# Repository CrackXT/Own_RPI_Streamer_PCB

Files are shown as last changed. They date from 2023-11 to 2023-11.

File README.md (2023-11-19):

# Own_RPI_Streamer_PCB

PCB files for RPI Streamer Board

# Description

This is a main board to hold a Raspberry Pi (4) and the Hifyberry Digi2 Pro expansion board. This puts the connections I need (for me) on one side to be able to build my own streamer.

- Part 1

The internal "power supply" (Pololu S13V30F5) delivers at 5V@3A, sensor and RGB are control by part 2.

There is a temperature sensor (Sensirion SHT45) under the SoC and an additional unregulated fan connector (e.g. Noctua NF-A4x20 5V). In addition there is the possibility to connect a lighting (RGB). Furthermore, the following connections are available... USB-C (power supply), USB-A 3.0 (data, e.g. USB stick with music on it), main switch, QWIIC/StemmaQT (sensor) and an external 5V connector (for part 2).

The board can be produced here (AISLER) with the files (.brd and .sch) or by any other PCB manufacturer. -> https://aisler.net/

# Spec

Vin: 2.8 - 22V<br>
Vout: 5V (typ., min.4,85V, max.5,15V)<br>
Iout: 3A<br>

# Serie

- .pro

# Layout

Top<br>


Bottom<br>


Routing/Dimensions(mm)<br>


Schematic<br>
Schematic as .pdf at the top of the page.

# License

Open hardware, use it, mod it, whatever you want, feel free...

# Thanks!

Own design and layout.

# Version - Build

v1.4 - 06.11.2023

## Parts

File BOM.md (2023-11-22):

# BOM - List

parts list for use<br>
[BOM_Streamer_v1.4.pdf](https://github.com/CrackXT/Own_RPI_Streamer_PCB/files/13402858/BOM_Streamer_v1.4.pdf)
<br>
BOM_Streamer_v1 4

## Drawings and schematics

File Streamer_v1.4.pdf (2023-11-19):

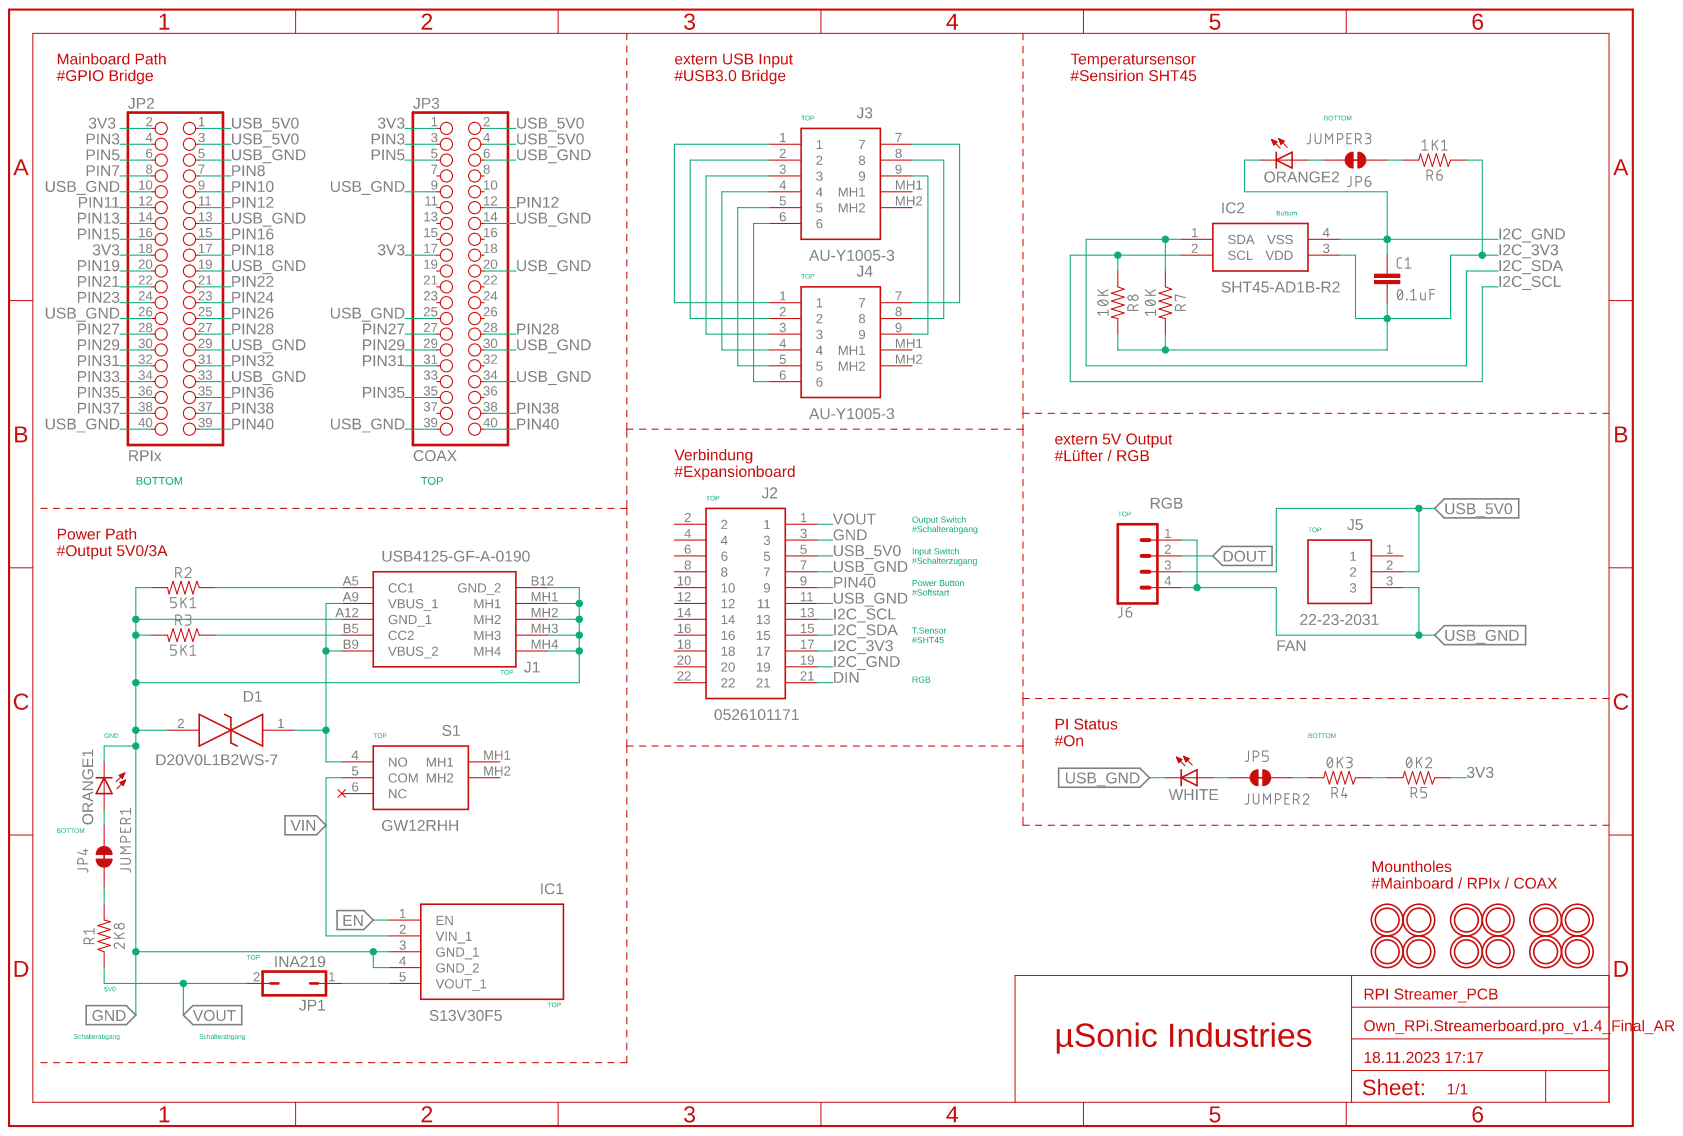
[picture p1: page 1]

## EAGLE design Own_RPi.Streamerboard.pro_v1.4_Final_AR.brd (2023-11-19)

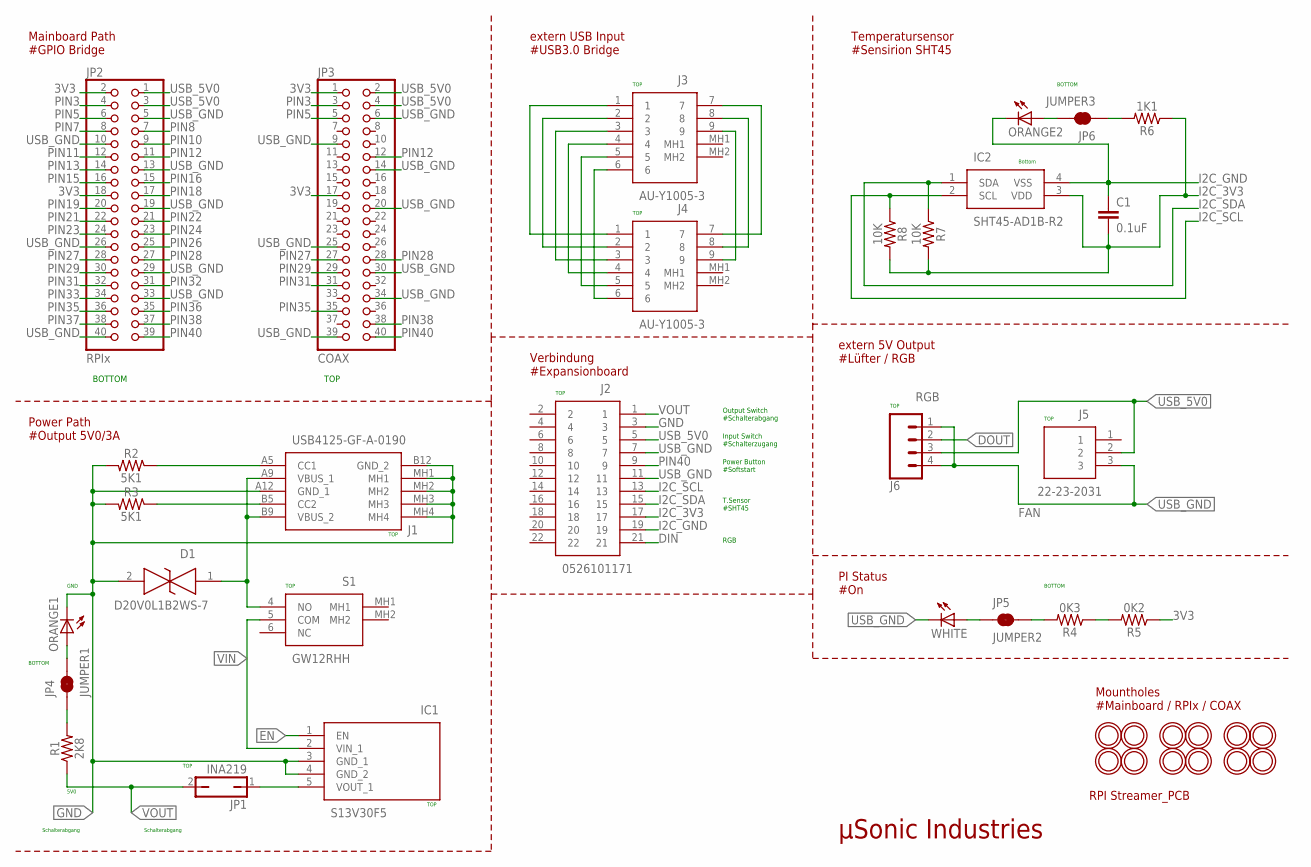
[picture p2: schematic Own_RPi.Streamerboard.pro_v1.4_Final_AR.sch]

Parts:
C1: 0.1uF; 0805
D1: D20V0L1B2WS-7; SOD2513X120N
IC1: S13V30F5
IC2: SHT45-AD1B-R2; SHT45AD1BR2
J1: USB4125-GF-A-0190; USB4125GFA0190
J2: 0526101171
J3, J4: AU-Y1005-3; AUY10053
J5: 22-23-2031; SHDR3W82P0X254_1X3_747X635X818
J6: CONN_041X04_NO_SILK; 1X04_NO_SILK
JP1: INA219; 1X02_NO_SILK
JP2: RPIx; 2X20-BIG
JP3: COAX; 2X20-BIG
JP4: JUMPER1; SMT-JUMPER_2_NC_TRACE_SILK
JP5: JUMPER2; SMT-JUMPER_2_NC_TRACE_SILK
JP6: JUMPER3; SMT-JUMPER_2_NC_TRACE_SILK
ORANGE1, ORANGE2: LEDCHIPLED_0805; CHIPLED_0805
R1: 2K8; 0805
R2, R3: 5K1; 0805
R4: 0K3; 0805
R5: 0K2; 0805
R6: 1K1; 0805
R7, R8: 10K; 0805
S1: GW12RHH
U$4, U$5, U$6, U$7, U$8, U$10, U$11, U$13, U$14, U$15, U$16, U$17: MOUNTINGHOLE2.5; MOUNTINGHOLE_2.5_PLATED
WHITE: LEDCHIPLED_0805; CHIPLED_0805

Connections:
3V3: JP2.2, JP2.18, JP3.1, JP3.17, R5.1
DIN: J2.21
DOUT: J6.2
EN: IC1.1 (EN)
GND: D1.2, IC1.3 (GND_1), IC1.4 (GND_2), J1.A12 (GND_1), J1.B12 (GND_2), J1.MH1, J1.MH2, J1.MH3, J1.MH4, J2.3, ORANGE1.C, R2.2, R3.2
I2C_3V3: C1.2, IC2.3 (VDD), J2.17, R6.1, R7.2, R8.2
I2C_GND: C1.1, IC2.4 (VSS), J2.19, ORANGE2.C
I2C_SCL: IC2.2 (SCL), J2.13, R8.1
I2C_SDA: IC2.1 (SDA), J2.15, R7.1
unnamed: JP4.1, R1.2
unnamed: R4.1, R5.2
unnamed: J1.B5 (CC2), R3.1
unnamed: J1.A5 (CC1), R2.1
unnamed: J3.4, J4.4
unnamed: JP6.2, ORANGE2.A
unnamed: JP5.1, WHITE.A
unnamed: IC1.5 (VOUT_1), JP1.1
unnamed: JP4.2, ORANGE1.A
unnamed: JP5.2, R4.2
unnamed: JP6.1, R6.2
unnamed: J3.6, J4.6
unnamed: J3.5, J4.5
unnamed: J3.3, J4.3
unnamed: J3.2, J4.2
unnamed: J3.1, J4.1
unnamed: J3.9, J4.9
unnamed: J3.8, J4.8
unnamed: J3.7, J4.7
PIN3: JP2.4, JP3.3
PIN5: JP2.6, JP3.5
PIN7: JP2.8
PIN8: JP2.7
PIN10: JP2.9
PIN11: JP2.12
PIN12: JP2.11, JP3.12
PIN13: JP2.14
PIN15: JP2.16
PIN16: JP2.15
PIN18: JP2.17
PIN19: JP2.20
PIN21: JP2.22
PIN22: JP2.21
PIN23: JP2.24
PIN24: JP2.23
PIN26: JP2.25
PIN27: JP2.28, JP3.27
PIN28: JP2.27, JP3.28
PIN29: JP2.30, JP3.29
PIN31: JP2.32, JP3.31
PIN32: JP2.31
PIN33: JP2.34
PIN35: JP2.36, JP3.35
PIN36: JP2.35
PIN37: JP2.38
PIN38: JP2.37, JP3.38
PIN40: J2.9, JP2.39, JP3.40
USB_5V0: J2.5, J5.2, J6.3, JP2.1, JP2.3, JP3.2, JP3.4
USB_GND: J2.7, J2.11, J5.3, J6.1, J6.4, JP2.5, JP2.10, JP2.13, JP2.19, JP2.26, JP2.29, JP2.33, JP2.40, JP3.6, JP3.9, JP3.14, JP3.20, JP3.25, JP3.30, JP3.34, JP3.39, WHITE.C
VBUS_VIN: D1.1, J1.A9 (VBUS_1), J1.B9 (VBUS_2), S1.4 (NO)
VIN: IC1.2 (VIN_1), S1.5 (COM)
VOUT: J2.1, JP1.2, R1.1

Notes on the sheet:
µSonic Industries
RPI Streamer_PCB
Power Path #Output 5V0/3A
TOP
Schalterabgang
BOTTOM
Mountholes #Mainboard / RPIx / COAX
GND
5V0
Temperatursensor #Sensirion SHT45
extern 5V Output #Lüfter / RGB
extern USB Input #USB3.0 Bridge
Mainboard Path #GPIO Bridge
PI Status #On
RGB
Bottom
Power Button #Softstart
Output Switch #Schalterabgang
Input Switch #Schalterzugang
T.Sensor #SHT45
Verbindung #Expansionboard
FAN

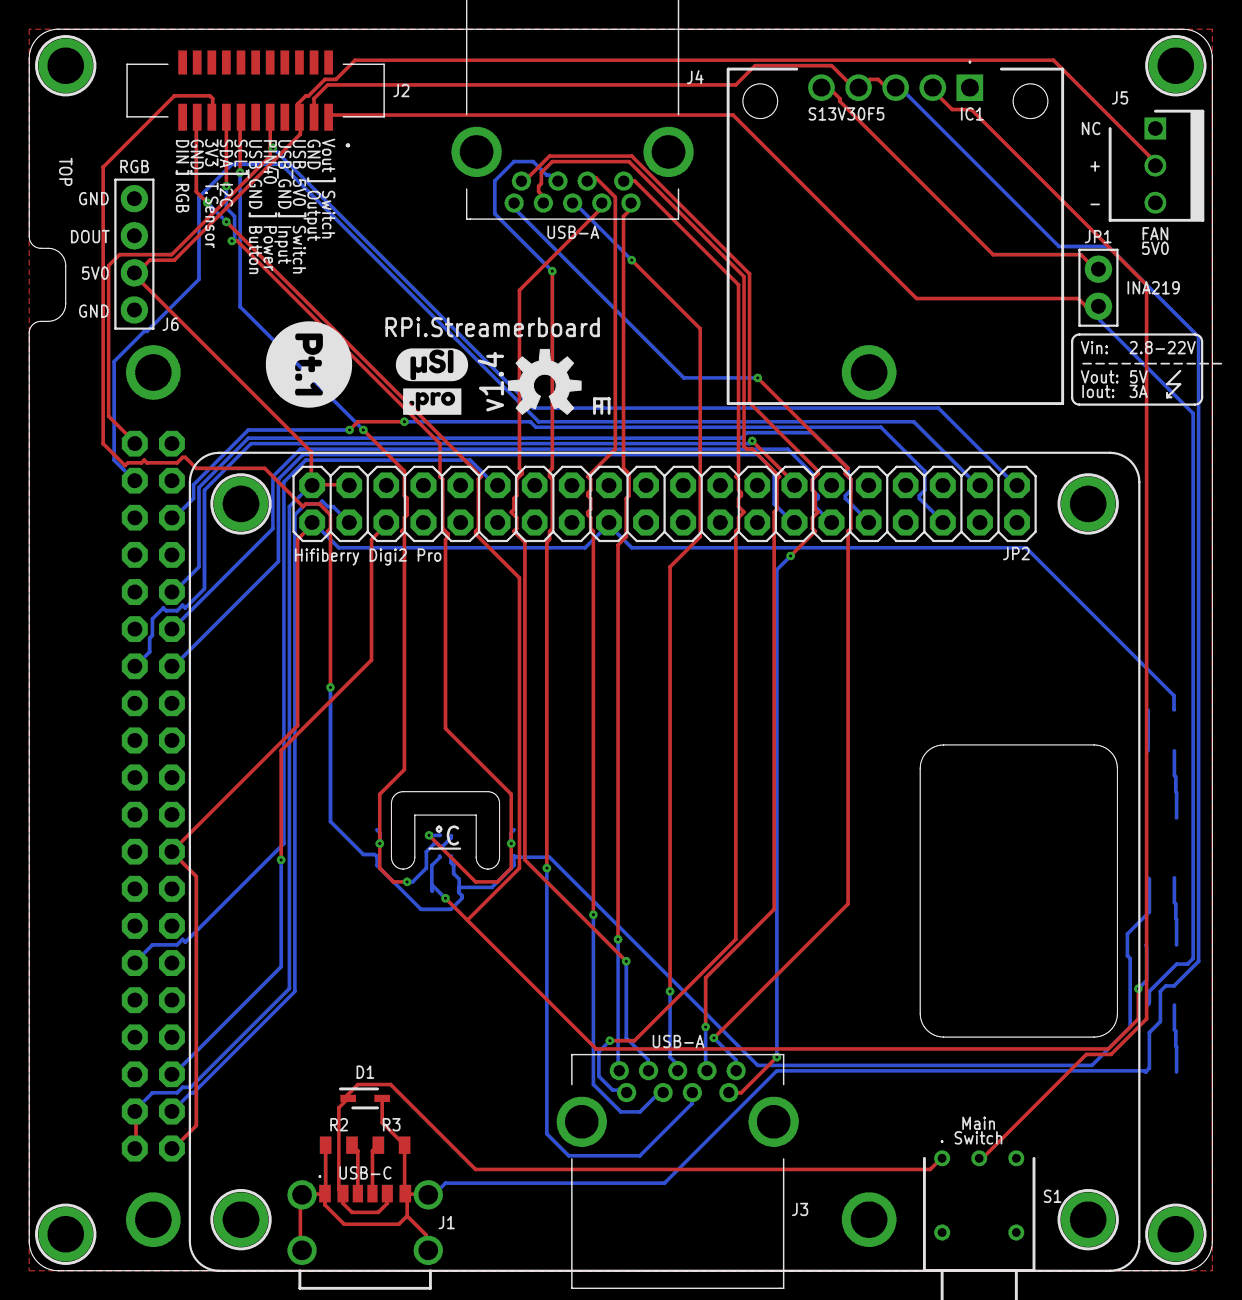
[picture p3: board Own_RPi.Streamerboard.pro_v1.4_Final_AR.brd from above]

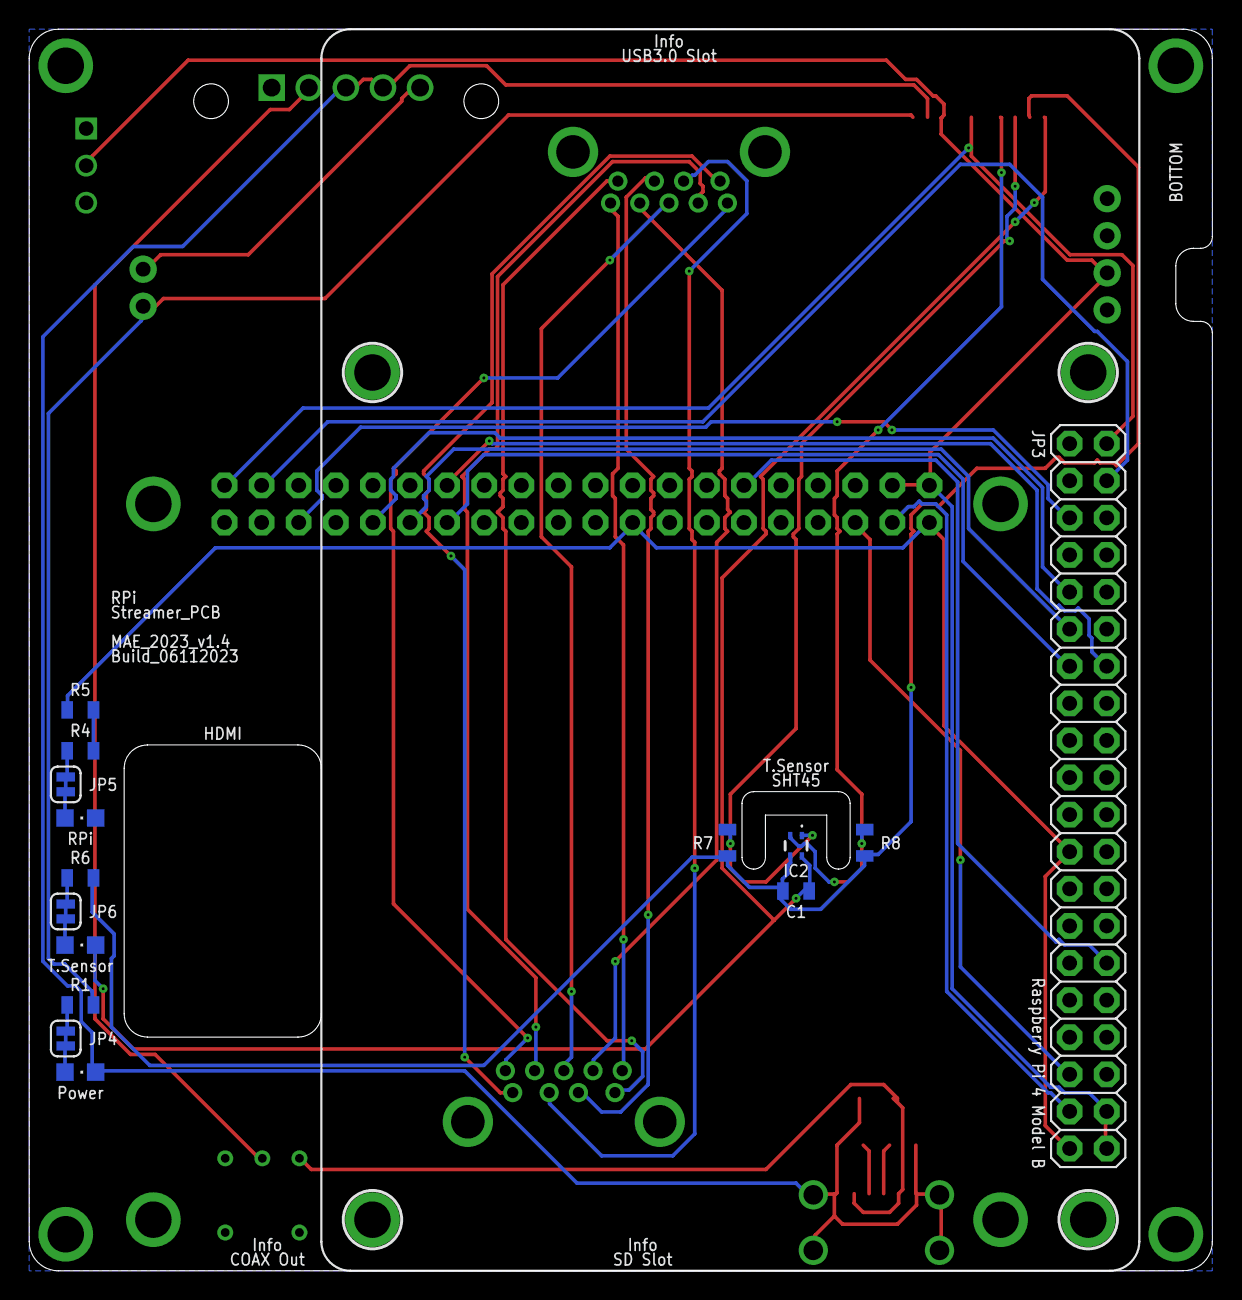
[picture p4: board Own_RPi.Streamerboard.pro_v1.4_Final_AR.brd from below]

Board: 2 copper layers, 81.0 x 85.0 mm, 44 parts (19 on the bottom side), 40 nets.

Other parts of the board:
U$1: .PRO_LARGE
U$2: OSHW-LOGO-M
U$3: PT.1
U$18: µSI_LARGE

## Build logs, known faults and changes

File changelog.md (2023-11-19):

# Version - Build
v1.0 - 08.07.2023
- First Release

v1.1 - 09.07.2023
- Schematic declaration corrected
- 500Ohm resistor splitted into 2 resistors
- designation adjusted
- dimensioning added
- Orintation notch added

v1.2 - 10.07.2023
- PIN decleration added
- cutout HDMI enlarged
- "power supply" specification on board
- Addition of designations

v1.3 - 21.10.2023
- optimize footprint S13V30f5
- switch from many "single" conntacts to one "big"
- USB-A Bottom crash with PI switch to TOP side
- RGB 1x4 new position
- solderability improved
- Designations corrected
- Component designation completed
- Measuring bridge integrated
- esd protection

v1.6 - 06.11.2023
- reduced from 13pin flex connector to 11pin
- LEDs can now be deactivated via detachable bridges

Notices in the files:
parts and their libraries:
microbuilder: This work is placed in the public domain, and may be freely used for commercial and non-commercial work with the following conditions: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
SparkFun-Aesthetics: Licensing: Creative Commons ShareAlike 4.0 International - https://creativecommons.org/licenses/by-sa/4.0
